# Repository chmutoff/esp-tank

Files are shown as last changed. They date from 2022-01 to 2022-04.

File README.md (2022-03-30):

# ESP Tank

This project allows to control any chassis with fixed wheels (like TP100 mini tank chassis or the famous 4wd chassis) using ESP32-CAM.

Some of the advantages:
- The chassis is controlled with a virtual joystick 
- It is possible to set the onboard flash led brightness
- Smooth camera control (up/down and left/right)
- There is an option to change camera resolution and image orientation

## Assembly
Connect the motor controller and two servos
| Part | ESP32-CAM Pin|
|--- |---
| Left motor A1 | 14 |
| Left motor B1 | 15 |
| Right motor A2 | 13 |
| Right motor B2 | 2  |
| Horizontal servo  | 12 |
| Vertical servo | 3  |

## Compilation
Change the `WIFI_SSID` and `WIFI_PASS` in `platrformio.ini` file or create a new file ending with `_env.ini` (i.e.: `my_env.ini`) to avoid git from overwriting your changes. You can also override the motor pins, servo pins, etc.. Full list of options will be available on the [project documentation page](https://chmutoff.github.io/esp-tank/).
```
[env:esp32cam-serial]
board = esp32cam
monitor_speed = 115200
upload_speed = 921600
board_build.partitions = min_spiffs.csv
build_flags =
    ${env.build_flags}
    -DWIFI_SSID="MyRealWifiName"
    -DWIFI_PASS="MyRealWifiPassword"
    -DCAMERA_MODEL="AI_THINKER"
```
Once the device is flashed, it is possilbe to use OTA. Example ota environment:
```
[env:esp32cam-ota]
board = esp32cam
monitor_speed = 115200
upload_protocol = espota
upload_port = 192.168.1.10
upload_flags =
    --port=3232
    --timeout=30
board_build.partitions = min_spiffs.csv
build_flags =
    ${env.build_flags}
    -DWIFI_SSID="MyRealWifiName"
    -DWIFI_PASS="MyRealWifiPassword"
    -DCAMERA_MODEL="AI_THINKER"
    -DCORE_DEBUG_LEVEL=3
```
## Testing
This project has 3 tests, one for verifying the flash led, another one to check the motors and the last one to check that servos are working fine.
Run tests one by one
```
pio test -e esp32cam-serial -f test_flash_led
pio test -e esp32cam-serial -f test_mc_servo
pio test -e esp32cam-serial -f test_mc_motor
```

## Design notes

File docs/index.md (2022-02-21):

## Building an ESP32 controlled chassis

The ESP TANK project is designed to be used with any custom combination of chassis, motors and power supply. This guide will describe the 2 most popular chassis from Aliexpress and the optimal way to get them up and running. If you decide to build your own chassis, the motor control driver must have 2 control pins for each motor. At the moment, the only tested board is [ESP32-CAM by AiThinker](http://www.ai-thinker.com/pro_view-24.html)

- [TP100 chassis with 12V battery](tp100-12v.md)
- [TP100 chassis with 3.7V battery](tp100-3.7v.md)
- [Acrylic chassis with 3.7V battery](acrylic-3.7v.md)

## Compile and upload the firmware
TODO: compilation chapter goes here

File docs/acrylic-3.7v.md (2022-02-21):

# 4WD acrylic car kit with 3.7V battery

## Part list
- Acrylic car kit (W: 15cm, H: 6cm, L: 25cm) with TT gear motors(3-6V, 90-200rpm)
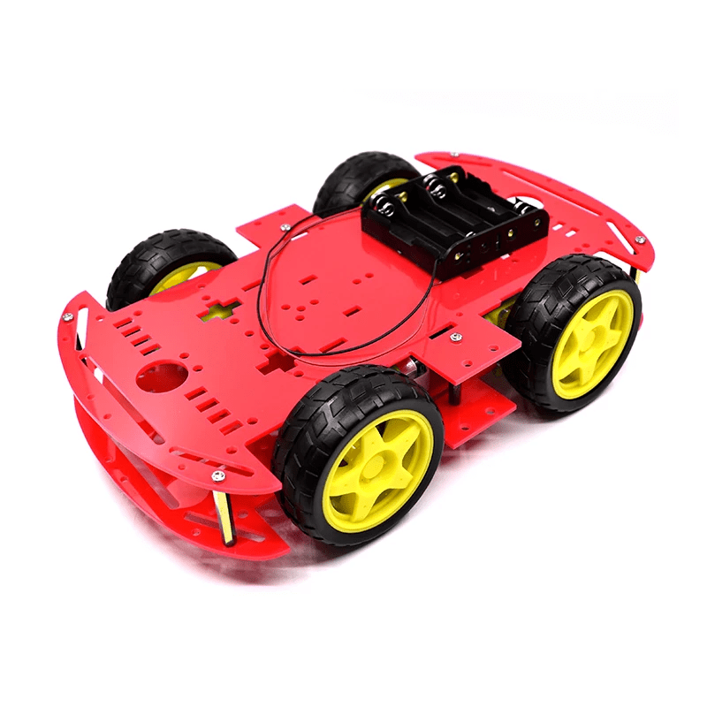
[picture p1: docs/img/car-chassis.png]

- 3.7V 18650 batteries
- 18650 battery holder. This chassis can fit 2x batteries between motors or more batteries on the top.
- BMS: 1S-3876 (5A). Battery protection MUST be installed for safety!
- Charger: TP4056 (1A) or IP2312 (3A). Optional, to charge the batteries on-board with a USB cable. In case of TP405, choose the version without integrated BMS or it will constantly turn off the power due to high starting current of the motors!
- Step-UP (boost) converter: SX1308 or MT3608
- Motor driver MX1508, TA6586, DRV8833, L9110S, TB6612 (Connect STBY, PWMA, PWMB to VCC pin) or L298N (low performance)
- 2x 470uF capacitors
- 2x 100nf (0.1uF) capacitor
- 2x Servo: SG90(plastic gear) or MG90(metalic gear)
- [ESP32-CAM by AiThinker](http://www.ai-thinker.com/pro_view-24.html)

## Schematic
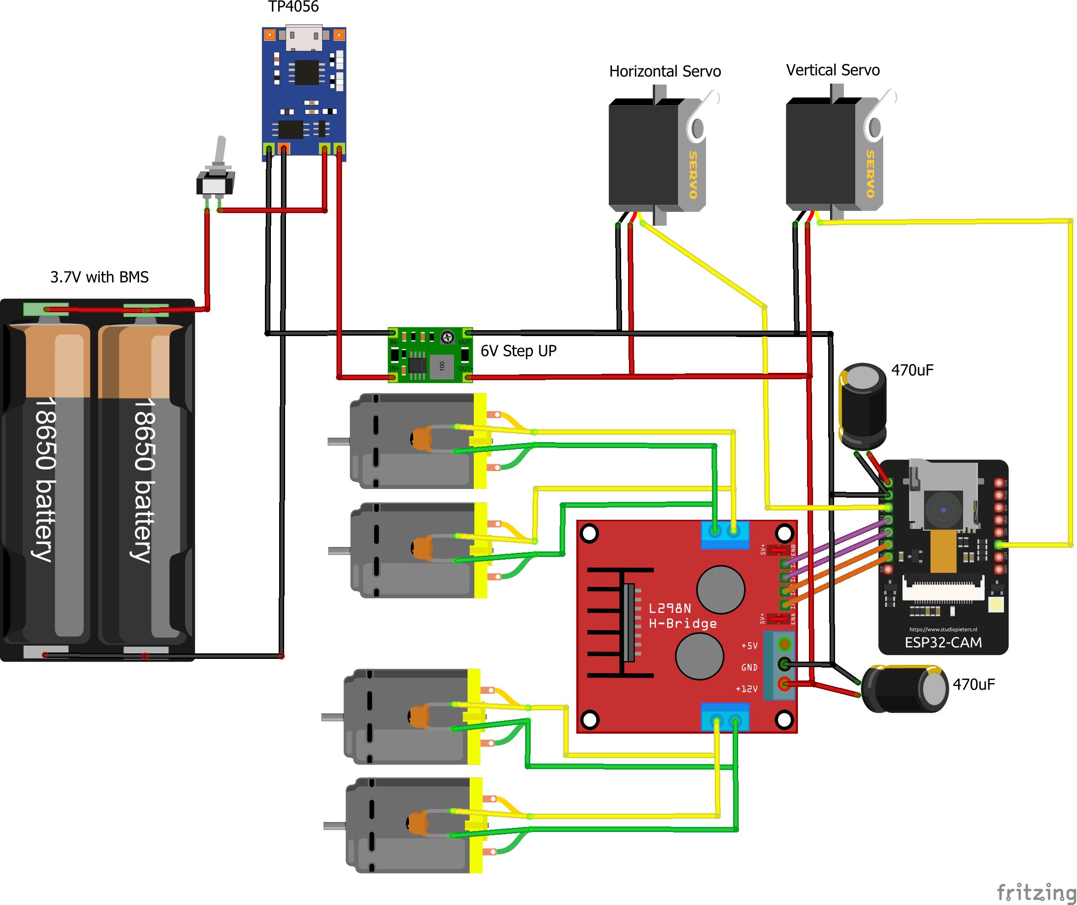
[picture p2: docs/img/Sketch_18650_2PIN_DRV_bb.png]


## Assembly
To attach a servo use standard servo pan/tilt mount with this [3D printed clip](https://www.thingiverse.com/thing:4934734)  
TODO: add assembly instructions with pictures

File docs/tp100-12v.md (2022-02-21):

# TP100 with 12V battery

## Part list
- Mini TP100 chassis (W: 15cm, H: 6cm, L: 20cm) with 33GB-520 motors (6-12V, 170-350rpm)
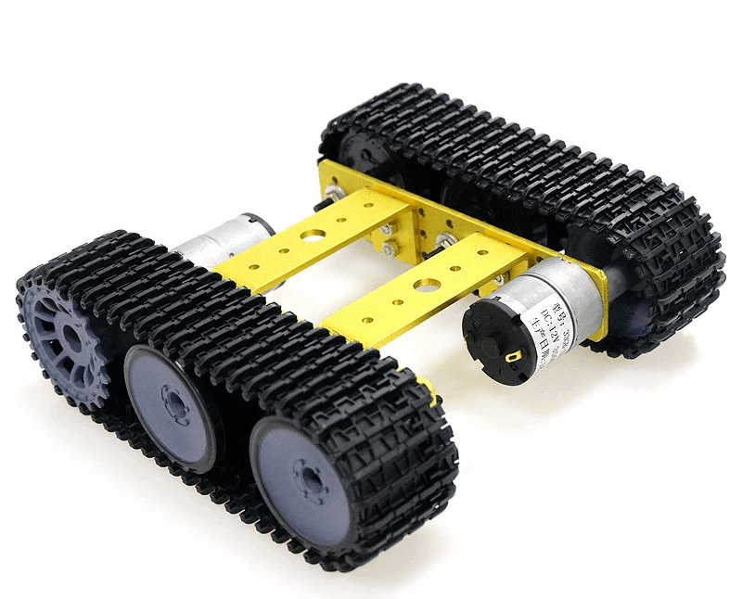
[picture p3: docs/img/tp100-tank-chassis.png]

- 12V Lithium battery or 3x 18650 in paralell. 
- Step down converter: MP1584EN, MP2315 or LM2596
- Motor driver: TA6586, L9110S, TB6612 (Connect STBY, PWMA, PWMB to VCC pin) or L298N (low performance)
- 2x 470uF capacitors
- 2x 100nf (0.1uF) capacitor
- 2x Servo: SG90(plastic gear) or MG90(metalic gear)
- [ESP32-CAM by AiThinker](http://www.ai-thinker.com/pro_view-24.html)

## Schematic
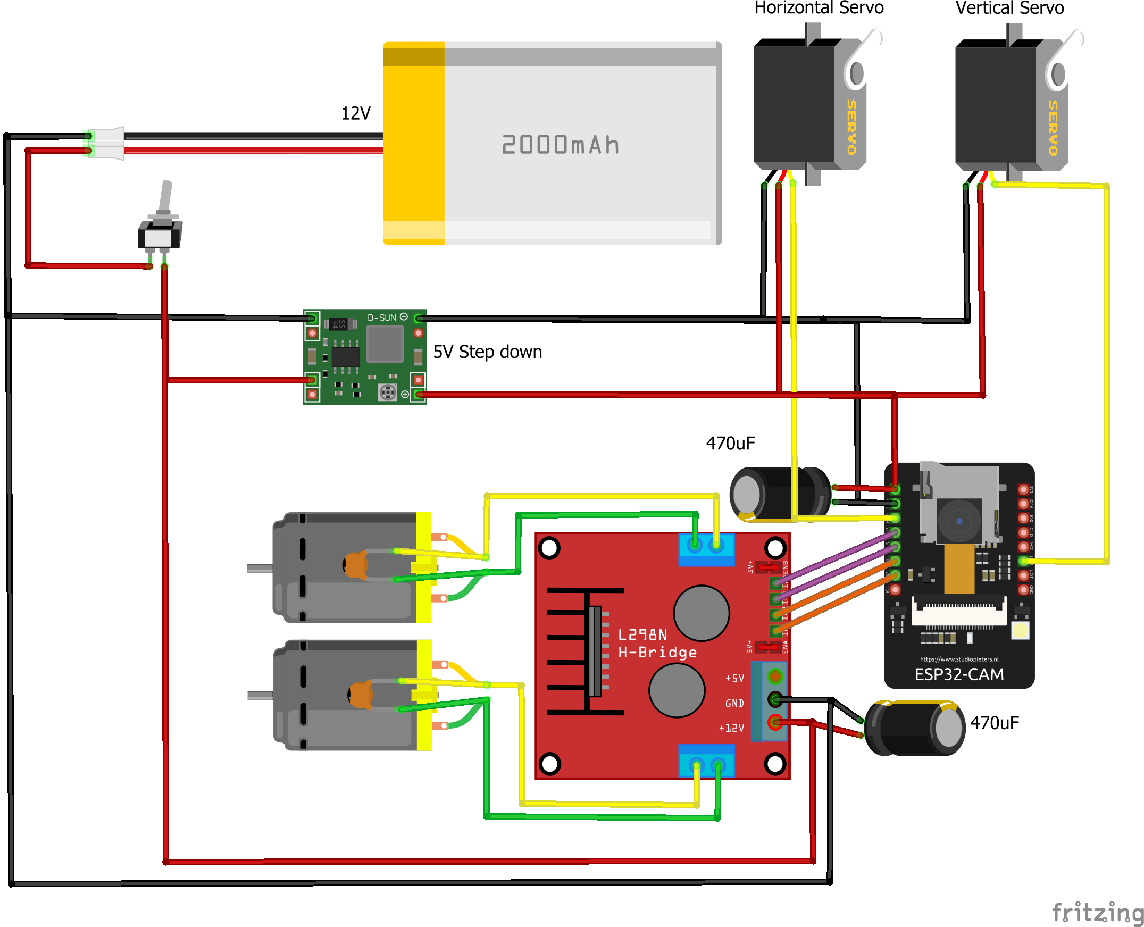
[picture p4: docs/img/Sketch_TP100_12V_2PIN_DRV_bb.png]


## Assembly
To attach a servo use standard servo pan/tilt mount with this [3D printed clip](https://www.thingiverse.com/thing:4934734)  
TODO: add assembly instructions with pictures

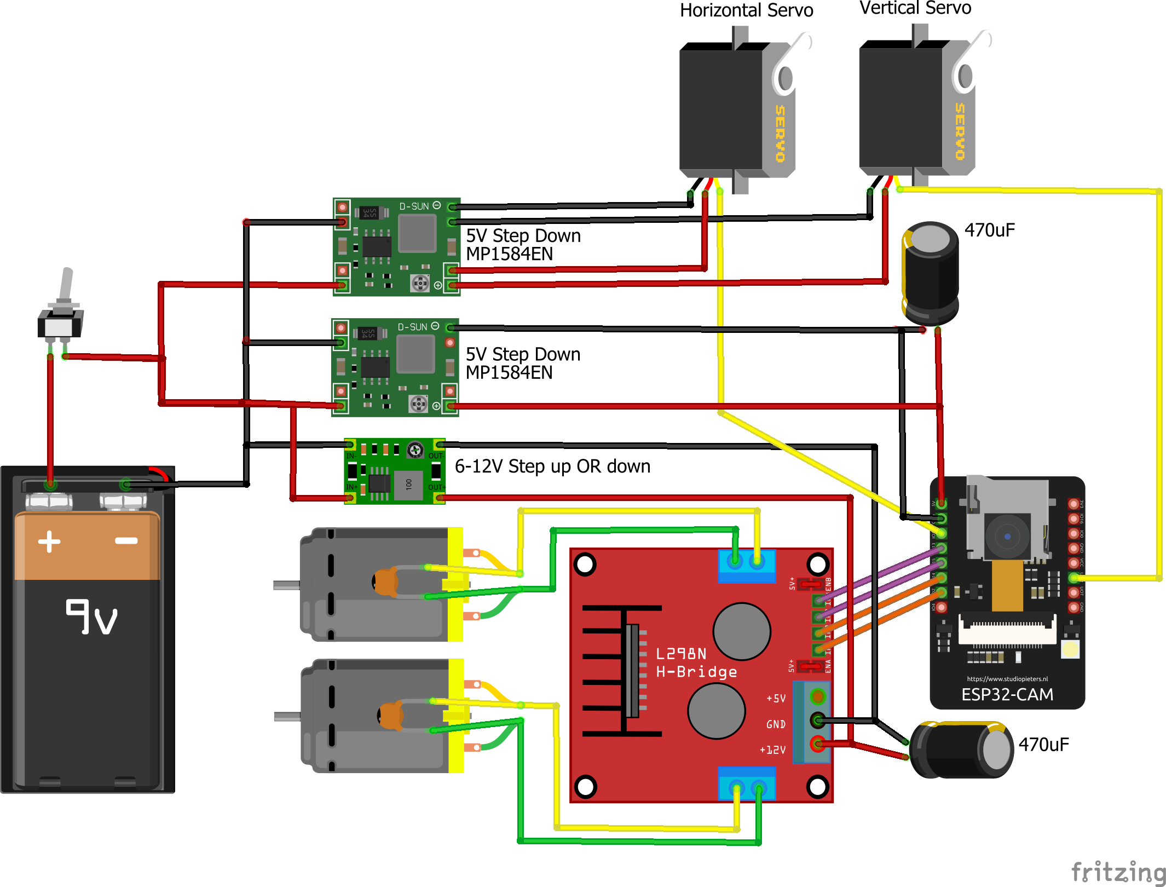
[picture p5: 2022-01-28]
docs/img/Sketch_9V_2PIN_DRV_bb.png

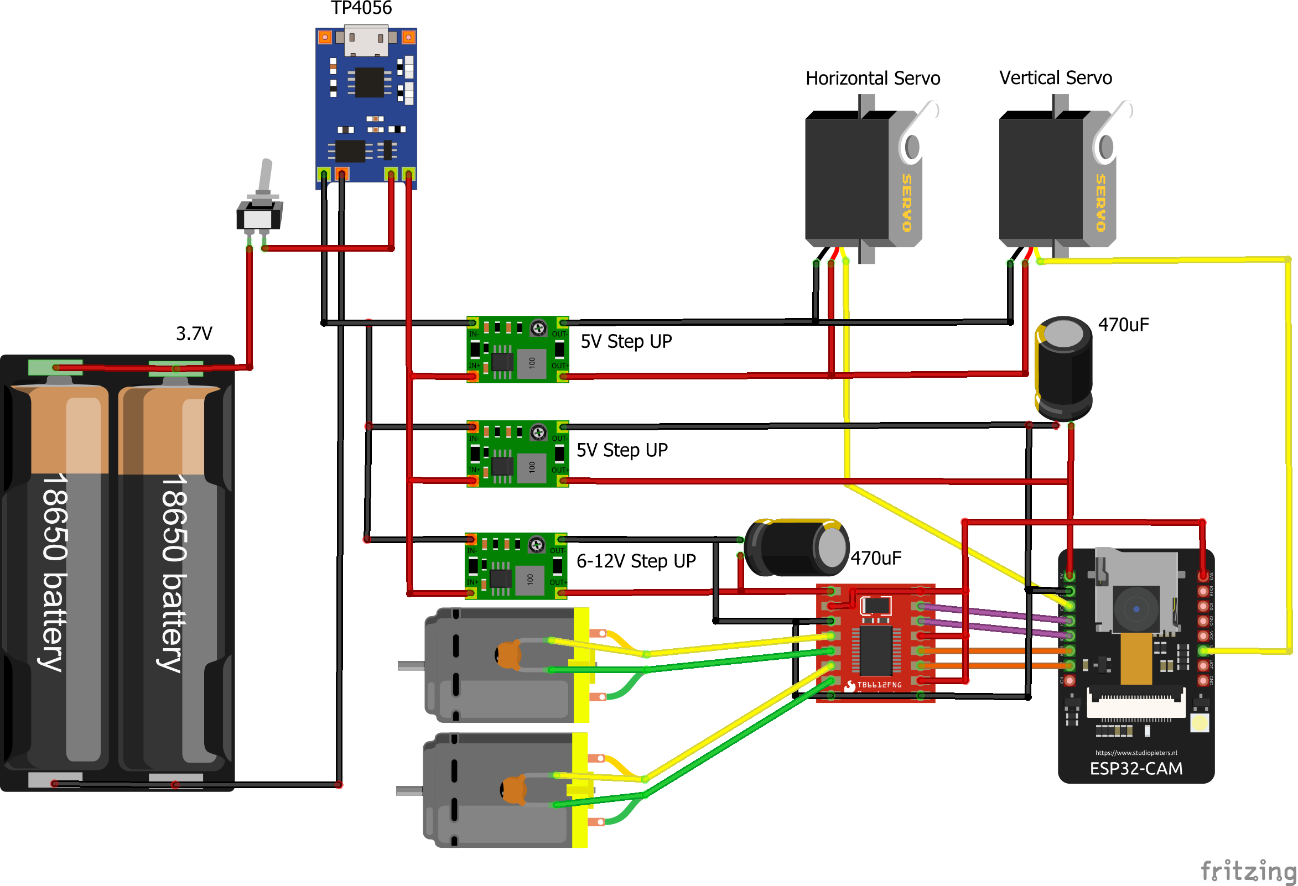
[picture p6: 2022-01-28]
docs/img/Sketch_18650_TB6612_bb.png

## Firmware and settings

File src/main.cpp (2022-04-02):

/**
 *
 * @file main.cpp
 * @author Anton Chmutov Derevianko <sir.antoxic@gmail.com>
 * @brief The entry point of the project
 *
 * @copyright (C) 2022 Anton Chmutov Derevianko <sir.antoxic@gmail.com>
 * This file is subject to the terms and conditions of the MIT license.
 * See the LICENSE file in the top level directory for more details.
 *
 */
#include <ArduinoOTA.h>
#include <WiFi.h>
#include "camera_pins.h"
#include "config.h"
#include "esp_camera.h"
#include "flash_led.h"
#include "mc_motor.h"
#include "mc_servo.h"

#ifdef DISABLE_BROWNOUT_DETECTION
#include "soc/soc.h"
#include "soc/rtc_cntl_reg.h"
#endif

mc_motor_dev_t motor_l;
mc_motor_dev_t motor_r;
mc_servo_dev_t servo_h;
mc_servo_dev_t servo_v;

void start_web_server();

void init_camera()
{
    camera_config_t config;
    config.ledc_channel = LEDC_CHANNEL_0;
    config.ledc_timer = LEDC_TIMER_0;
    config.pin_d0 = Y2_GPIO_NUM;
    config.pin_d1 = Y3_GPIO_NUM;
    config.pin_d2 = Y4_GPIO_NUM;
    config.pin_d3 = Y5_GPIO_NUM;
    config.pin_d4 = Y6_GPIO_NUM;
    config.pin_d5 = Y7_GPIO_NUM;
    config.pin_d6 = Y8_GPIO_NUM;
    config.pin_d7 = Y9_GPIO_NUM;
    config.pin_xclk = XCLK_GPIO_NUM;
    config.pin_pclk = PCLK_GPIO_NUM;
    config.pin_vsync = VSYNC_GPIO_NUM;
    config.pin_href = HREF_GPIO_NUM;
    config.pin_sscb_sda = SIOD_GPIO_NUM;
    config.pin_sscb_scl = SIOC_GPIO_NUM;
    config.pin_pwdn = PWDN_GPIO_NUM;
    config.pin_reset = RESET_GPIO_NUM;
    config.xclk_freq_hz = 20000000;
    config.pixel_format = PIXFORMAT_JPEG;

    // if PSRAM IC present, init with UXGA resolution and higher JPEG quality
    //                      for larger pre-allocated frame buffer.
    if (psramFound())
    {
        config.frame_size = FRAMESIZE_UXGA;
        config.jpeg_quality = 10;
        config.fb_count = 2;
    }
    else
    {
        log_w("NO PSRAM found");
        config.frame_size = FRAMESIZE_SVGA;
        config.jpeg_quality = 12;
        config.fb_count = 1;
    }

#if (CAMERA_MODEL == ESP_EYE)
    pinMode(13, INPUT_PULLUP);
    pinMode(14, INPUT_PULLUP);
#endif

    esp_err_t err = esp_camera_init(&config);
    if (err != ESP_OK)
    {
        log_e("Camera init failed with error 0x%x", err);
        return;
    }

    sensor_t *s = esp_camera_sensor_get();

#ifdef CAM_VFLIP
    s->set_vflip(s, 1);
#endif

#ifdef CAM_HMIRROR
    s->set_hmirror(s, 1);
#endif

    // initial sensors are flipped vertically and colors are a bit saturated
    if (s->id.PID == OV3660_PID)
    {
#ifdef CAM_VFLIP
        s->set_vflip(s, 0);
#else
        s->set_vflip(s, 1); // flip it back
#endif
        s->set_brightness(s, 1);  // up the brightness just a bit
        s->set_saturation(s, -2); // lower the saturation
    }

    s->set_framesize(s, FRAMESIZE_QVGA);

#if (CAMERA_MODEL == M5STACK_WIDE || CAMERA_MODEL == M5STACK_ESP32CAM)
#ifdef CAM_VFLIP
    s->set_vflip(s, 0);
#else
    s->set_vflip(s, 1);
#endif
#ifdef CAM_HMIRROR
    s->set_hmirror(s, 0);
#else
    s->set_hmirror(s, 1);

#endif
#endif
}

void init_ota()
{
    ArduinoOTA.setPort(3232);

    ArduinoOTA.setHostname(host_name);

    if (strlen(ota_password) > 0)
    {
        ArduinoOTA.setPassword(ota_password);
    }

    ArduinoOTA.onStart([]()
                       {
                            String type;
                            if (ArduinoOTA.getCommand() == U_FLASH)
                            {
                                type = "sketch";
                            }
                            else
                            { // U_SPIFFS
                                type = "filesystem";
                            }

                            esp_camera_deinit();

                            // NOTE: if updating SPIFFS this would be the place to unmount SPIFFS using SPIFFS.end()
                            log_i("Start updating %s", type); });

    ArduinoOTA.onEnd([]()
                     { log_i("OTA end"); });

    ArduinoOTA.onProgress([](unsigned int progress, unsigned int total)
                          { log_i("Progress: %u%%\r", (progress / (total / 100))); });

    ArduinoOTA.onError([](ota_error_t error)
                       {
                           log_e("Error[%u]: ", error);
                           if (error == OTA_AUTH_ERROR)
                           {
                               Serial.println("Auth Failed");
                           }
                           else if (error == OTA_BEGIN_ERROR)
                           {
                               Serial.println("Begin Failed");
                           }
                           else if (error == OTA_CONNECT_ERROR)
                           {
                               Serial.println("Connect Failed");
                           }
                           else if (error == OTA_RECEIVE_ERROR)
                           {
                               Serial.println("Receive Failed");
                           }
                           else if (error == OTA_END_ERROR)
                           {
                               Serial.println("End Failed");
                           } });

    ArduinoOTA.begin();
    log_i("OTA initialized");
}

void setup()
{
#ifdef DISABLE_BROWNOUT_DETECTION
    WRITE_PERI_REG(RTC_CNTL_BROWN_OUT_REG, 0); // disable brownout detector
#endif
    Serial.begin(115200);

    init_camera();

    // Flash LED init
    flash_led_init(FLASH_LED_PIN, FLASH_LED_LEDC_CHANNEL);

    // Motor init
    mc_motor_init(&motor_l, MOTOR_L_PIN_A, MOTOR_L_PIN_B, 500, MOTOR_L_MIN_DUTY, MCPWM_U0_O0);
    mc_motor_init(&motor_r, MOTOR_R_PIN_A, MOTOR_R_PIN_B, 500, MOTOR_R_MIN_DUTY, MCPWM_U0_O1);

    // Servo init
    mc_servo_init(&servo_h, SERVO_H_PIN, SERVO_H_MIN_PULSEWIDTH_US, SERVO_H_MAX_PULSEWIDTH_US, SERVO_H_MAX_DEGREE, MCPWM_U0_A2, 90);
    mc_servo_init(&servo_v, SERVO_V_PIN, SERVO_V_MIN_PULSEWIDTH_US, SERVO_V_MAX_PULSEWIDTH_US, SERVO_V_MAX_DEGREE, MCPWM_U0_B2, 90);

    WiFi.setHostname(host_name);
    WiFi.enableSTA(true);
    WiFi.begin(wifi_ssid, wifi_pass);

    log_i("Connecting to Wifi \"%s\"", wifi_ssid);

    pinMode(BUILTIN_LED_PIN, OUTPUT);
    while (WiFi.status() != WL_CONNECTED)
    {
        digitalWrite(BUILTIN_LED_PIN, LOW);
        delay(200);
        digitalWrite(BUILTIN_LED_PIN, HIGH);
        delay(200);
    }
    digitalWrite(BUILTIN_LED_PIN, LOW);

    log_i("WiFi connected. RSSI: %d", WiFi.RSSI());

    start_web_server();
    init_ota();

    log_i("System ready! Use 'http://%s' to connect", WiFi.localIP().toString().c_str());
}

extern int64_t last_control_request;
int64_t last_reconnect = 0;
int64_t last_servo_move = 0;
bool builtin_led_status = true;

void loop()
{
    ArduinoOTA.handle();

    // If we don't get any control command > 200ms then we stop!
    if (esp_timer_get_time() - last_control_request >= 200000)
    {
        mc_motor_set_speed(&motor_l, 0);
        mc_motor_set_speed(&motor_r, 0);
    }

    // When WiFi is lost, reconnect every 200ms
    if (WiFi.status() != WL_CONNECTED)
    {
        if (esp_timer_get_time() - last_reconnect >= 200000)
        {
            WiFi.reconnect();
            digitalWrite(BUILTIN_LED_PIN, builtin_led_status);
            builtin_led_status = !builtin_led_status;
            last_reconnect = esp_timer_get_time();
        }
    }
    else
    {
        digitalWrite(BUILTIN_LED_PIN, LOW);
    }

    // Smoothly move servos to target position
    if (esp_timer_get_time() - last_servo_move >= 20000) // 20ms
    {
        mc_servo_move_to_target(&servo_h);
        mc_servo_move_to_target(&servo_v);

        last_servo_move = esp_timer_get_time();
    }
}

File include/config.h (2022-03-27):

#ifndef __CONFIG_H
#define __CONFIG_H

#define STRINGIFY(x) #x
#define TO_STRING(x) STRINGIFY(x) // Convert preprocessor macro to string

#ifndef WIFI_SSID
const char *wifi_ssid = "MyWifiNetworkName";
#else
const char *wifi_ssid = TO_STRING(WIFI_SSID);
#endif

#ifndef WIFI_PASS
const char *wifi_pass = "MyWifiNetworkPassword";
#else
const char *wifi_pass = TO_STRING(WIFI_PASS);
#endif

#ifndef MDNS_HOST_NAME
const char *host_name = "esp-tank";
#else
const char *host_name = TO_STRING(MDNS_HOST_NAME);
#endif

#ifndef OTA_PASSWORD
const char *ota_password = "";
#else
const char *ota_password = TO_STRING(OTA_PASSWORD);
#endif

#ifndef FLASH_LED_PIN
#define FLASH_LED_PIN 4
#endif
#ifndef FLASH_LED_LEDC_CHANNEL
#define FLASH_LED_LEDC_CHANNEL LEDC_CHANNEL_7 // free ledc PWM channel
#endif

#ifndef BUILTIN_LED_PIN
#define BUILTIN_LED_PIN 33
#endif

#ifndef MOTOR_L_PIN_A
#define MOTOR_L_PIN_A 14 // Left motor A
#endif
#ifndef MOTOR_L_PIN_B
#define MOTOR_L_PIN_B 15 // Left motor B
#endif
#ifndef MOTOR_L_MIN_DUTY
#define MOTOR_L_MIN_DUTY 25 // Minimal duty in %
#endif

#ifndef MOTOR_R_PIN_A
#define MOTOR_R_PIN_A 13 // Right motor A
#endif
#ifndef MOTOR_R_PIN_B
#define MOTOR_R_PIN_B 2 // Right motor B
#endif
#ifndef MOTOR_R_MIN_DUTY
#define MOTOR_R_MIN_DUTY 25 // Minimal duty in %
#endif

#ifndef SERVO_H_PIN
#define SERVO_H_PIN 12 // Pin of the vertical servo
#endif
#ifndef SERVO_H_MIN_PULSEWIDTH_US
#define SERVO_H_MIN_PULSEWIDTH_US (1000) // Minimum pulse width in microsecond
#endif
#ifndef SERVO_H_MAX_PULSEWIDTH_US
#define SERVO_H_MAX_PULSEWIDTH_US (2000) // Maximum pulse width in microsecond
#endif
#ifndef SERVO_H_MAX_DEGREE
#define SERVO_H_MAX_DEGREE (180) // Maximum angle in degree upto which servo can rotate
#endif

#ifndef SERVO_V_PIN
#define SERVO_V_PIN 3 // Pin of the horizontal servo
#endif
#ifndef SERVO_V_MIN_PULSEWIDTH_US
#define SERVO_V_MIN_PULSEWIDTH_US (1000) // Minimum pulse width in microsecond
#endif
#ifndef SERVO_V_MAX_PULSEWIDTH_US
#define SERVO_V_MAX_PULSEWIDTH_US (2000) // Maximum pulse width in microsecond
#endif
#ifndef SERVO_V_MAX_DEGREE
#define SERVO_V_MAX_DEGREE (180) // Maximum angle in degree upto which servo can rotate
#endif

#endif /* __CONFIG_H */

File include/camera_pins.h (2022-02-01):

#define WROVER_KIT 1
#define ESP_EYE 2
#define M5STACK_PSRAM 3
#define M5STACK_V2_PSRAM 4
#define M5STACK_WIDE 5
#define M5STACK_ESP32CAM 6
#define AI_THINKER 7
#define TTGO_T_JOURNAL 8

//
// WARNING!!! PSRAM IC required for UXGA resolution and high JPEG quality
//            Ensure ESP32 Wrover Module or other board with PSRAM is selected
//            Partial images will be transmitted if image exceeds buffer size
//

#if (CAMERA_MODEL == WROVER_KIT)
#define PWDN_GPIO_NUM    -1
#define RESET_GPIO_NUM   -1
#define XCLK_GPIO_NUM    21
#define SIOD_GPIO_NUM    26
#define SIOC_GPIO_NUM    27

#define Y9_GPIO_NUM      35
#define Y8_GPIO_NUM      34
#define Y7_GPIO_NUM      39
#define Y6_GPIO_NUM      36
#define Y5_GPIO_NUM      19
#define Y4_GPIO_NUM      18
#define Y3_GPIO_NUM       5
#define Y2_GPIO_NUM       4
#define VSYNC_GPIO_NUM   25
#define HREF_GPIO_NUM    23
#define PCLK_GPIO_NUM    22

#elif (CAMERA_MODEL == ESP_EYE)
#define PWDN_GPIO_NUM    -1
#define RESET_GPIO_NUM   -1
#define XCLK_GPIO_NUM    4
#define SIOD_GPIO_NUM    18
#define SIOC_GPIO_NUM    23

#define Y9_GPIO_NUM      36
#define Y8_GPIO_NUM      37
#define Y7_GPIO_NUM      38
#define Y6_GPIO_NUM      39
#define Y5_GPIO_NUM      35
#define Y4_GPIO_NUM      14
#define Y3_GPIO_NUM      13
#define Y2_GPIO_NUM      34
#define VSYNC_GPIO_NUM   5
#define HREF_GPIO_NUM    27
#define PCLK_GPIO_NUM    25

#elif (CAMERA_MODEL == M5STACK_PSRAM)
#define PWDN_GPIO_NUM     -1
#define RESET_GPIO_NUM    15
#define XCLK_GPIO_NUM     27
#define SIOD_GPIO_NUM     25
#define SIOC_GPIO_NUM     23

#define Y9_GPIO_NUM       19
#define Y8_GPIO_NUM       36
#define Y7_GPIO_NUM       18
#define Y6_GPIO_NUM       39
#define Y5_GPIO_NUM        5
#define Y4_GPIO_NUM       34
#define Y3_GPIO_NUM       35
#define Y2_GPIO_NUM       32
#define VSYNC_GPIO_NUM    22
#define HREF_GPIO_NUM     26
#define PCLK_GPIO_NUM     21

#elif (CAMERA_MODEL == M5STACK_V2_PSRAM)
#define PWDN_GPIO_NUM     -1
#define RESET_GPIO_NUM    15
#define XCLK_GPIO_NUM     27
#define SIOD_GPIO_NUM     22
#define SIOC_GPIO_NUM     23

#define Y9_GPIO_NUM       19
#define Y8_GPIO_NUM       36
#define Y7_GPIO_NUM       18
#define Y6_GPIO_NUM       39
#define Y5_GPIO_NUM        5
#define Y4_GPIO_NUM       34
#define Y3_GPIO_NUM       35
#define Y2_GPIO_NUM       32
#define VSYNC_GPIO_NUM    25
#define HREF_GPIO_NUM     26
#define PCLK_GPIO_NUM     21

#elif (CAMERA_MODEL == M5STACK_WIDE)
#define PWDN_GPIO_NUM     -1
#define RESET_GPIO_NUM    15
#define XCLK_GPIO_NUM     27
#define SIOD_GPIO_NUM     22
#define SIOC_GPIO_NUM     23

#define Y9_GPIO_NUM       19
#define Y8_GPIO_NUM       36
#define Y7_GPIO_NUM       18
#define Y6_GPIO_NUM       39
#define Y5_GPIO_NUM        5
#define Y4_GPIO_NUM       34
#define Y3_GPIO_NUM       35
#define Y2_GPIO_NUM       32
#define VSYNC_GPIO_NUM    25
#define HREF_GPIO_NUM     26
#define PCLK_GPIO_NUM     21

#elif (CAMERA_MODEL == M5STACK_ESP32CAM)
#define PWDN_GPIO_NUM     -1
#define RESET_GPIO_NUM    15
#define XCLK_GPIO_NUM     27
#define SIOD_GPIO_NUM     25
#define SIOC_GPIO_NUM     23

#define Y9_GPIO_NUM       19
#define Y8_GPIO_NUM       36
#define Y7_GPIO_NUM       18
#define Y6_GPIO_NUM       39
#define Y5_GPIO_NUM        5
#define Y4_GPIO_NUM       34
#define Y3_GPIO_NUM       35
#define Y2_GPIO_NUM       17
#define VSYNC_GPIO_NUM    22
#define HREF_GPIO_NUM     26
#define PCLK_GPIO_NUM     21

#elif (CAMERA_MODEL == AI_THINKER)
#define PWDN_GPIO_NUM     32
#define RESET_GPIO_NUM    -1
#define XCLK_GPIO_NUM      0
#define SIOD_GPIO_NUM     26
#define SIOC_GPIO_NUM     27

#define Y9_GPIO_NUM       35
#define Y8_GPIO_NUM       34
#define Y7_GPIO_NUM       39
#define Y6_GPIO_NUM       36
#define Y5_GPIO_NUM       21
#define Y4_GPIO_NUM       19
#define Y3_GPIO_NUM       18
#define Y2_GPIO_NUM        5
#define VSYNC_GPIO_NUM    25
#define HREF_GPIO_NUM     23
#define PCLK_GPIO_NUM     22

#elif (CAMERA_MODEL == TTGO_T_JOURNAL)
#define PWDN_GPIO_NUM      0
#define RESET_GPIO_NUM    15
#define XCLK_GPIO_NUM     27
#define SIOD_GPIO_NUM     25
#define SIOC_GPIO_NUM     23

#define Y9_GPIO_NUM       19
#define Y8_GPIO_NUM       36
#define Y7_GPIO_NUM       18
#define Y6_GPIO_NUM       39
#define Y5_GPIO_NUM        5
#define Y4_GPIO_NUM       34
#define Y3_GPIO_NUM       35
#define Y2_GPIO_NUM       17
#define VSYNC_GPIO_NUM    22
#define HREF_GPIO_NUM     26
#define PCLK_GPIO_NUM     21

#else
#error "Camera model not selected"
#endif

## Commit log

2022-01-16 Added code for simple (pwm) motor control
2022-01-18 Changed motor pins. Added motor test mode
2022-01-19 Right motor PWM bug fix
2022-01-21 Added initial code for servo
2022-01-22 Improved servo code
2022-01-23 Added servo to web interface
2022-01-23 LED light code refactor
2022-01-24 Added small servo library
2022-01-24 Refactored servo code to use servo lib
2022-01-25 Added simple motor library using mcpwm
2022-01-28 Added project sketches
    [Sketch_18650_2PIN_DRV.fzz, Sketch_18650_TB6612.fzz, Sketch_9V_2PIN_DRV.fzz]
2022-01-28 Improved TB6612 sketch
    [Sketch_18650_TB6612.fzz]
2022-01-28 Added chassis images
2022-02-02 Improved flash led code
2022-02-06 Added builtin LED
2022-02-06 flash_led.cpp: replaced print with log. bugfix.
2022-02-06 Simplified servo initialization
2022-02-07 Added motor duty params
2022-02-07 Simplified motor init
2022-02-08 Changed motor pins to avoid motor start on boot
    [config.h]
2022-02-10 Improved camera code. Framesize. Small cleanup.
2022-02-10 Replaced print with log_
    [main.cpp]
2022-02-10 Turn off motors on receive timeout
2022-02-13 Added smoth servo movement
2022-02-13 Added option to disable brownout detection
    [main.cpp]
2022-02-21 Create tp100-12v
2022-02-21 Added TP100-12V sketch
    [Sketch_TP100_12V_2PIN_DRV.fzz]
2022-02-21 Updated sketch
    [Sketch_18650_2PIN_DRV.fzz]
2022-03-21 main.cpp: Image resolution(framesize) BugFIX
    [main.cpp]
2022-03-22 httpd.cpp: optimized camera stream handler
2022-03-22 main.cpp: OTA improvement. Fixed a bug where OTA would not work if the camera stream is open.
    [main.cpp]
2022-03-22 index_html.cpp: improved camera image size
2022-03-30 httpd.cpp: fixed typo in file name
    [httpd.cpp]
2022-04-02 main.cpp: added VFLIP and HMIRROR camera options
